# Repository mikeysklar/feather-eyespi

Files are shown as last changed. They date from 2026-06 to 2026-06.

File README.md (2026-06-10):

# feather-eyespi

A plus-size FeatherWing base board that accepts an Adafruit Feather and breaks out an EYESPI connector for eInk and TFT displays.

Working with a lot of eInk and TFT displays means constantly re-wiring the EYESPI cable. This adapter cuts out that step — plug the Feather in, plug the display in, done. Single-sided board with minimal routing to keep assembly straightforward.

### BOM

| Part | Package | 
|---|---|
| EYESPI | 18-pin FPC connector 
| headers | Female 2.54mm vertical SMT 
| Resistor, 0Ω | 0805 

### EYESPI Connected to eInk

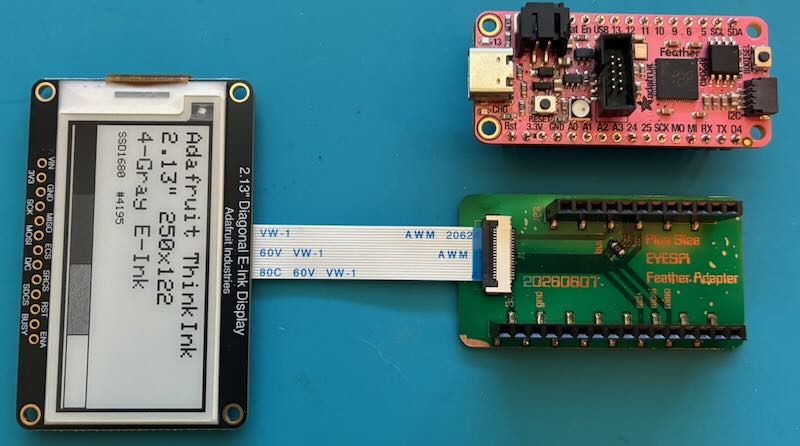
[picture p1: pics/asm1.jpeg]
asm1


---

### Assembled

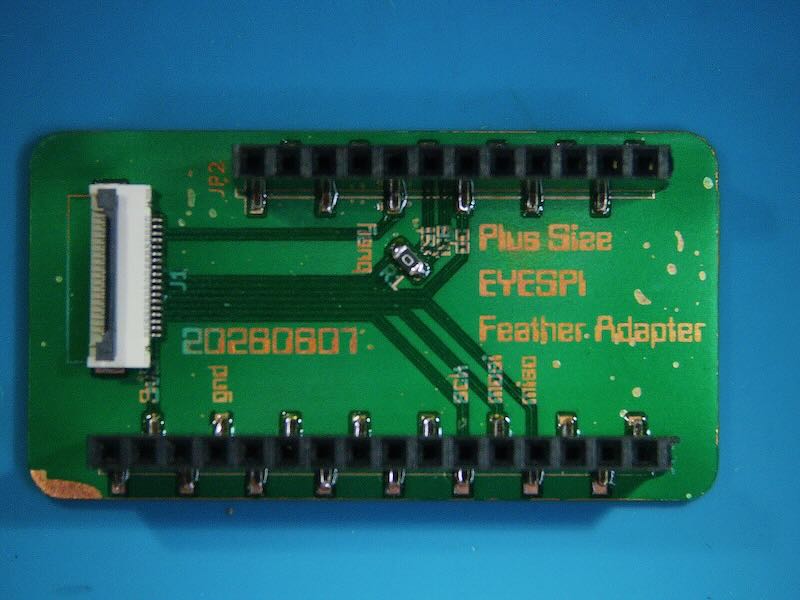
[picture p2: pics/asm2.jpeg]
asm2


---

### 18-pin FPC 

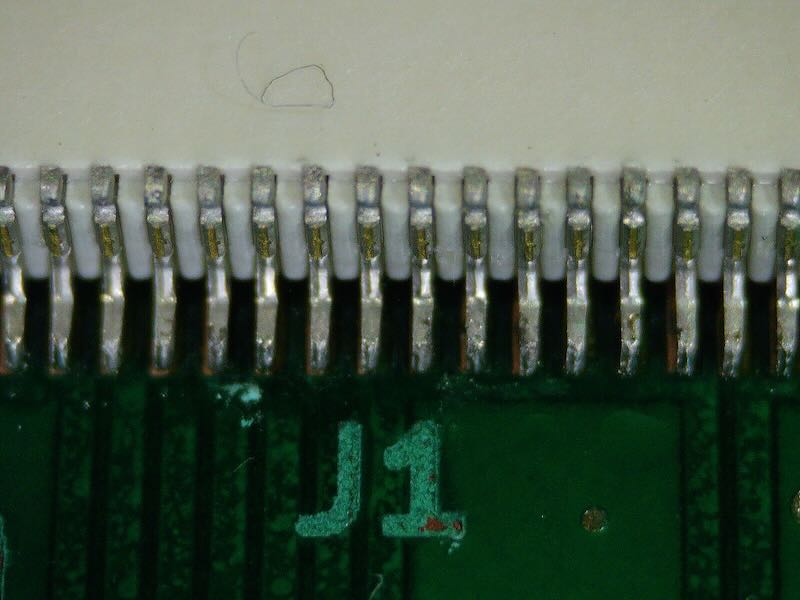
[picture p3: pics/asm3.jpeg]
asm3


---

### Metal Business Card Stencil

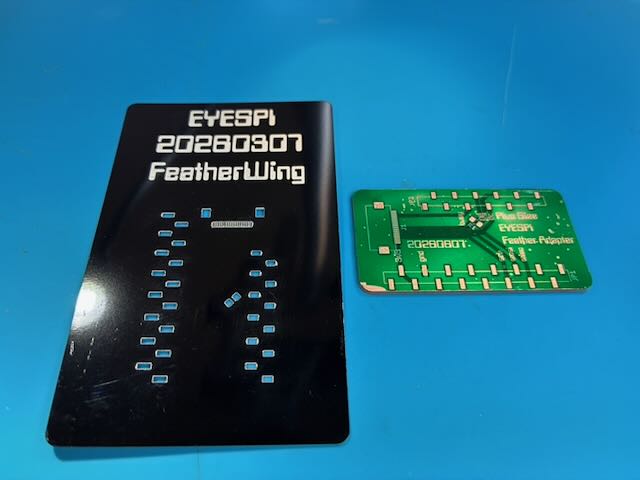
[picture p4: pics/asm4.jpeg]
asm4


---

### Finish PCB Silk / Mask Etched

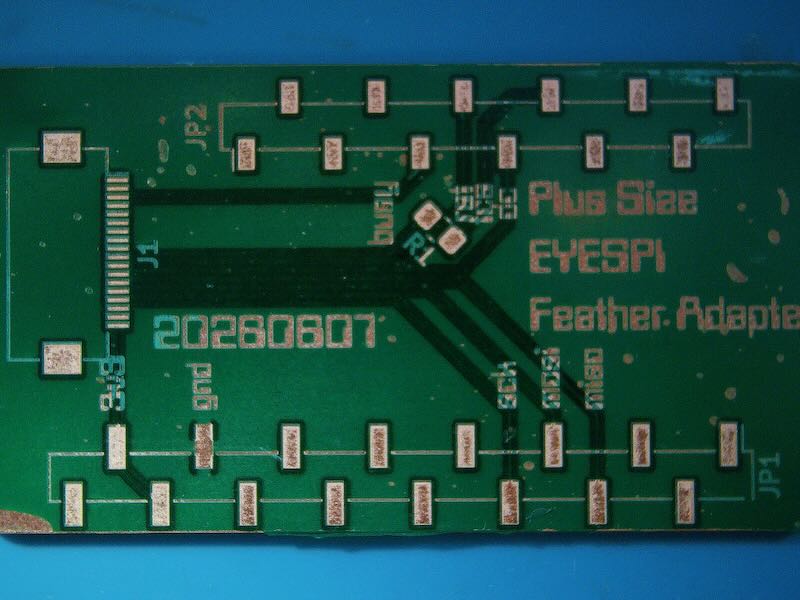
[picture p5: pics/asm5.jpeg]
asm5


---

### Wiring

| Feather Pin | Net | EYESPI Pin | Function |
|---|-----|---|---|
| SCK | sck | 15 | SPI clock |
| MOSI | mosi | 14 | SPI data out |
| MISO | miso | 13 | SPI data in |
| D11 | rst | 11 | Reset |
| D10 | dc | 12 | Data / Command |
| D12 | busy | 3 | Busy / Ready |
| D9 | tcs | 10 | TCS chip select |
| 3V3 | 3v3 | 18 | 3.3V power |
| GND | gnd | 16 | Ground |

---

### Fiber Laser Etched PCB 

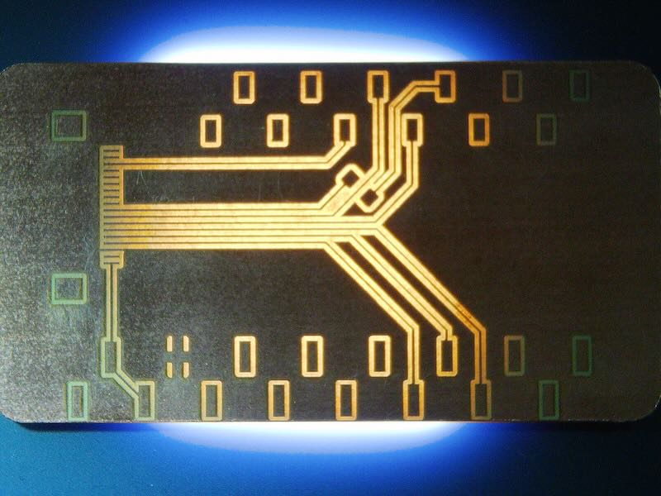
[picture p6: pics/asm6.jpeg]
asm6


---

### Backside board ID

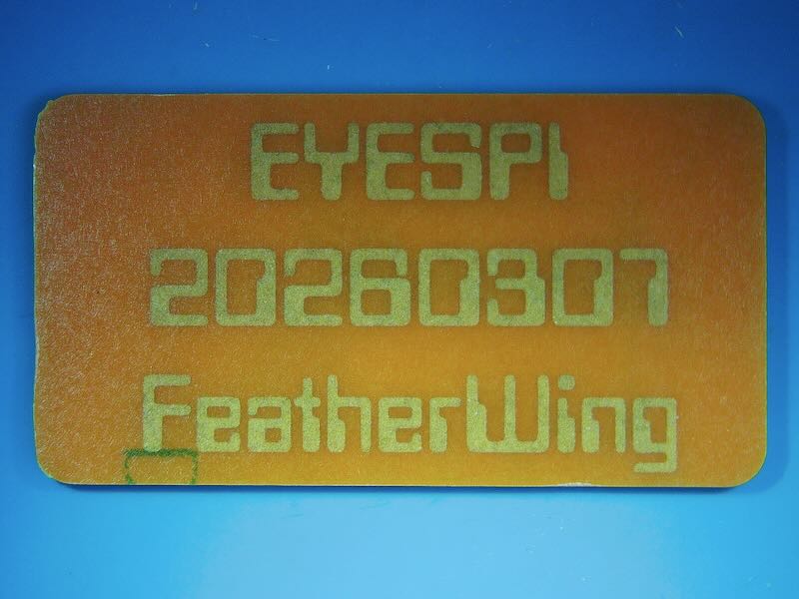
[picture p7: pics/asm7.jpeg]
asm7


---

### KiCAD PCB

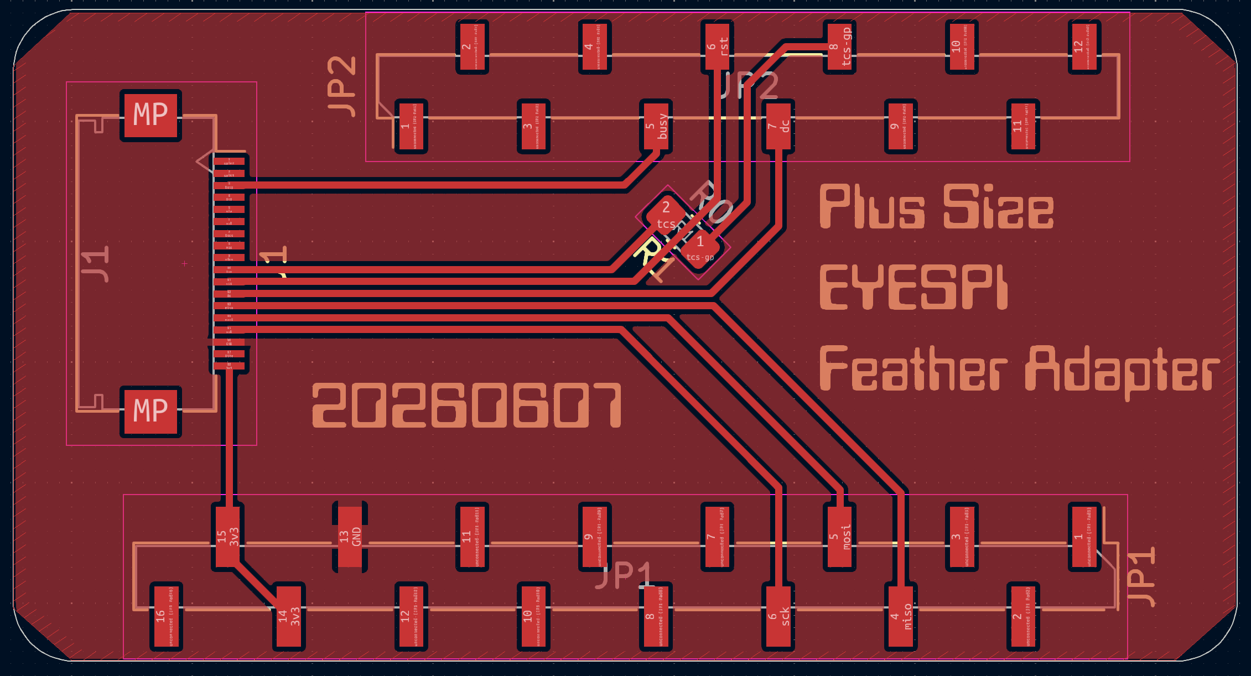
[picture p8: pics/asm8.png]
asm8


---

## License

This project is licensed under the GNU General Public License v3.0 — see the [LICENSE](LICENSE) file for details.

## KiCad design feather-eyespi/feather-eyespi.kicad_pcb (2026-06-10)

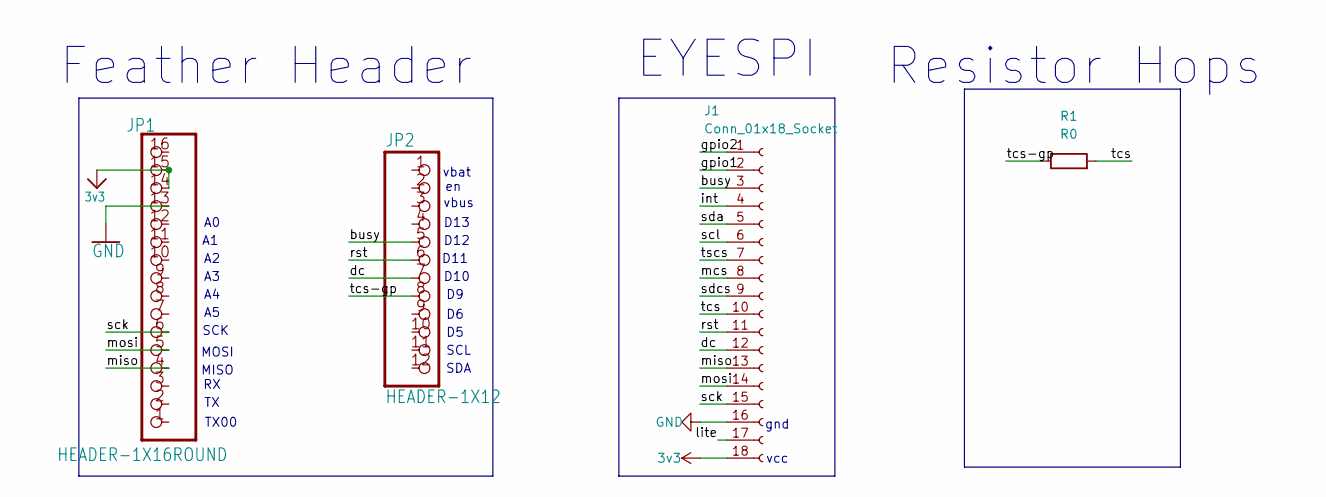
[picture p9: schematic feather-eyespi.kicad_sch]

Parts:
J1: Conn_01x18_Socket; Hirose_FH12-18S-0.5SH_1x18-1MP_P0.50mm_Horizontal
JP1: HEADER-1X16ROUND; PinHeader_1x16_P2.54mm_Vertical_SMD_Pin1Left
JP2: HEADER-1X12; PinSocket_1x12_P2.54mm_Vertical_SMD_Pin1Left
R1: R0; R_0805_2012Metric_Pad1.20x1.40mm_HandSolder

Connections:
3v3: J1.18, JP1.14, JP1.15
/busy: J1.3, JP2.5
/dc: J1.12, JP2.7
/gpio1: J1.2
/gpio2: J1.1
/int: J1.4
/lite: J1.17
/mcs: J1.8
/miso: J1.13, JP1.4
/mosi: J1.14, JP1.5
/rst: J1.11, JP2.6
/sck: J1.15, JP1.6
/scl: J1.6
/sda: J1.5
/sdcs: J1.9
/tcs: J1.10, R1.2
/tcs-gp: JP2.8, R1.1
/tscs: J1.7
GND: J1.16, JP1.13

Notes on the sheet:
SCK
D13
Resistor Hops
D12
D11
vcc
SCL
D10
vbus
Feather Header
SDA
vbat
gnd
TX00
MISO
EYESPI
MOSI

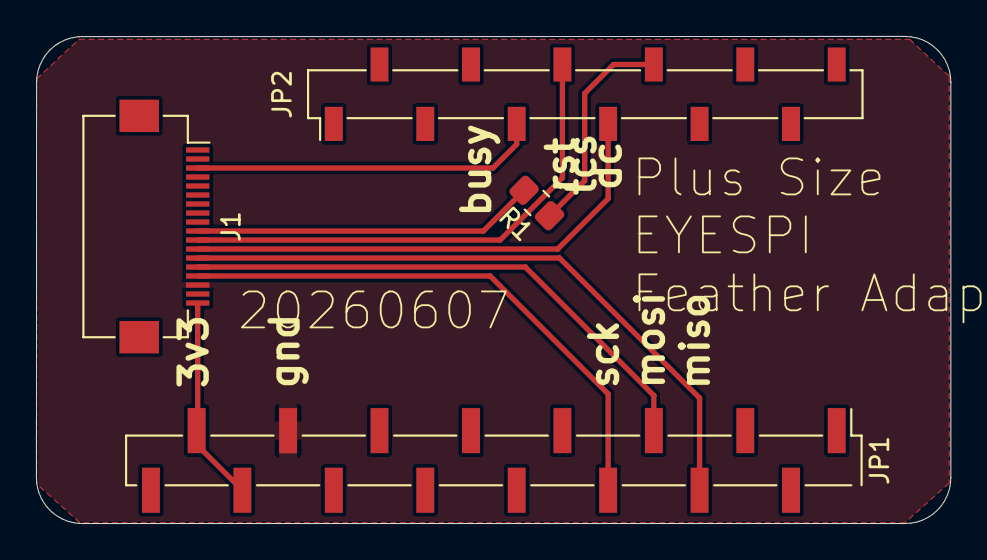
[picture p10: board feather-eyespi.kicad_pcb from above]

Board: 2 copper layers, 50.8 x 27.1 mm, 4 parts (0 on the bottom side), 10 nets.

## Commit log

2026-06-10 Initial commit: feather-eyespi KiCad PCB design with assembly photos
    [feather-eyespi.kicad_pcb, feather-eyespi.kicad_sch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]
2026-06-10 Add project summary and BOM to README
2026-06-10 Simplify BOM table to part and package only
2026-06-10 Add assembly photo descriptions to README
2026-06-10 Add KiCad schematic export (SVG + PDF) and schematic section in README
2026-06-10 Replace schematic image with plain text wiring table
2026-06-10 Remove generated schematic SVG and PDF
2026-06-10 Update README wiring table and reorder sections
